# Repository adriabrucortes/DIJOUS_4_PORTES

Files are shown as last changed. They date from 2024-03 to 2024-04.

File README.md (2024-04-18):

View this project on [CADLAB.io](https://cadlab.io/project/27987). 

# Projecte Eines de Disseny - PORTES
#### Adrià Brú, Miquel Limón, Lluís Pujadas

## Especificacions/Components

| Type | Name | Datasheet | Link | Price |
| --- | --- | --- | --- | --- |
| uC | PIC32MK0256MCJ048 | [uC](https://ww1.microchip.com/downloads/aemDocuments/documents/MCU32/ProductDocuments/DataSheets/PIC32MK-General-Purpose-and-Motor-Control-With-CAN-FD-Family-DataSheet-D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) | [Mouser](https://www.mouser.es/ProductDetail/Microchip-Technology/PIC32MK0256MCJ048-E-Y8X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) | 7,37 € |
| LDO 3.3V (3A) | LT1528CT#PBF | [LDO](https://rocelec.widen.net/view/pdf/nbjrjihvdn/LITCS09222-1.pdf?t.download=true&u=5oefqw) | [Digikey](https://www.digikey.es/en/products/detail/rochester-electronics-llc/LT1528CT-PBF/13481919) | 5,75 € |
| Motor (588Nm, 280mA) | HG37-200-AA-00 | [motor](https://www.mouser.es/datasheet/2/972/hg37-2525173.pdf) | [Mouser](https://www.mouser.es/ProductDetail/Nidec-Components/HG37-200-AA-00?qs=Wj%2FVkw3K%252BMBRymxOaiVRvg%3D%3D) | 26,74 € |
| CAN Transciever | TCAN3413DR | [can](https://www.ti.com/lit/ds/symlink/tcan3414.pdf?ts=1711721678762&ref_url=https%253A%252F%252Fwww.mouser.it%252F) | [Mouser](https://www.mouser.es/ProductDetail/Texas-Instruments/TCAN3413DR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) | 2,41 € |
| Crystal Osc | ECS-3225SMV-080-GP-TR | [clk](https://www.mouser.es/datasheet/2/122/ECS_3225SMV-1623609.pdf) | [Mouser](https://www.mouser.es/ProductDetail/ECS/ECS-3225SMV-080-GP-TR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) | 1,92 € |
| Driver (3.5A, +csense) | MAX22201ATC+ | [driver](https://www.mouser.es/datasheet/2/609/MAX22201_MAX22207-3127854.pdf) | [Mouser](https://www.mouser.es/ProductDetail/Analog-Devices-Maxim-Integrated/MAX22201ATC%2b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) | 1,56 € |
| ~~Current sensor (75A)~~ | ~~TMCS1123B2AQDVGR~~  | ~~[csense](https://www.ti.com/lit/ds/symlink/tmcs1123.pdf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)~~ | ~~[Mouser](https://www.mouser.es/ProductDetail/Texas-Instruments/TMCS1123B2AQDVGR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)~~ | ~~5,63 €~~ |
| Zener 12V (150MW) | DDZ9699T-7 | [zener](https://eu.mouser.com/datasheet/2/115/DIOD_S_A0003550665_1-2542209.pdf) | [Mouser](https://eu.mouser.com/ProductDetail/Diodes-Incorporated/DDZ9699T-7?qs=mQbszxtPdlOBwg08InvD3Q%3D%3D) | 0,41 € |
| Díode | BYV10MX-600PQ | [diode](https://eu.mouser.com/datasheet/2/848/BYV10MX_600P-2401273.pdf) | [Mouser](https://eu.mouser.com/ProductDetail/WeEn-Semiconductors/BYV10MX-600PQ?qs=QNEnbhJQKvYwaGjd%2F4%252BPWg%3D%3D) | 0,54 € |
| RFID | DLP-RFID2 | [rfid](https://mm.digikey.com/Volume0/opasdata/d220001/medias/docus/5656/DLP-RFID2%28D%29-V2.pdf) | [Digikey](https://www.digikey.es/en/products/detail/dlp-design-inc/DLP-RFID2/3770244) | 35,04 € |
| Motor lineal (150N, 2A) (opc) | DLA-12-5-A-50-IP65 | [motor-lineal](https://www.transmotec.com/Download/Catalog/Transmotec-EN-DLA-2022.pdf) | [Transmotec](https://www.transmotec.com/product/dla-12-5-a-50-pot-ip65/) | 303,5 € |
| Final de Carrera  (5V) | ESE-22MV21T | [Final-Carrera](https://industrial.panasonic.com/cdbs/www-data/pdf/ATB0000/ATB0000C12.pdf) | [Digikey](https://www.digikey.es/en/products/detail/panasonic-electronic-components/ESE-22MV21T/1245478) | 0,42 € |
| DC/DC 5V (2A, +/-49.5mV) | P7805-2000R-S | [dcdc2A](https://eu.mouser.com/datasheet/2/670/p78_2000r_s-3070500.pdf) | [Mouser](https://eu.mouser.com/ProductDetail/CUI-Inc/P7803-2000R-S?qs=vvQtp7zwQdObalelOc2Obw%3D%3D) | 5,53 € |
| DC/DC 3.3V (3A, +/-33.3mV) | P783-Q24-S3-S | [dcdc3A](https://eu.mouser.com/datasheet/2/670/p783_s-1889817.pdf) | [Mouser](https://eu.mouser.com/ProductDetail/CUI-Inc/P783-Q24-S3-S?qs=sPbYRqrBIVl7G8uy4wpmww%3D%3D) | 15,07 € |
| C Tan 1u 20V 3216-18 | T491A105K020AT4360 | [ctant1u](https://eu.mouser.com/datasheet/2/447/KEM_T2005_T491-3316937.pdf) | [Mouser](https://eu.mouser.com/ProductDetail/KEMET/T491A105K020AT4360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) | 0,07 € |
| C Cer 22u 10V 1206 | CL31B226KPHNNWE | [cer22u](https://eu.mouser.com/datasheet/2/585/MLCC-1837944.pdf) | [Mouser](https://eu.mouser.com/ProductDetail/Samsung-Electro-Mechanics/CL31B226KPHNNWE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) | 0,086 € |
| C Cer 22u 50V | KTS500B226M76N0T00 | [ccer22u50v](https://eu.mouser.com/datasheet/2/420/nipc_s_a0010886389_1-2285932.pdf) | [Mouser](https://eu.mouser.com/ProductDetail/Chemi-Con/KTS500B226M76N0T00?qs=yFwz03cOJpkGGSneI4ka0Q%3D%3D) | 3,58 € |
| C Cer 10n 25V 1206 | KAM31BR81H103KT | [ccer10n50v](https://eu.mouser.com/datasheet/2/40/AutoMLCCKAM-3216307.pdf) | [Mouser](https://eu.mouser.com/ProductDetail/KYOCERA-AVX/KAM31BR81H103KT?qs=Jm2GQyTW%2FbjzijSUJGW%2FJA%3D%3D) | 0,28 € |
| C Ele 4.7u 35V | 865080540002 | [cele4.7u](https://www.we-online.com/components/products/datasheet/865080540002.pdf) | [Mouser](https://eu.mouser.com/ProductDetail/Wurth-Elektronik/865080540002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) | 0,17 € |
| C Ele 47u 16V | 860010372004 | [cele74u](https://www.we-online.com/components/products/datasheet/860010372004.pdf) | [Mouser](https://www.mouser.es/ProductDetail/Wurth-Elektronik/860010372004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) | 0,09 € |
| C Cer 1u 25V 0805 | C0805C105K3RAC | [cer1u25v](https://www.mouser.es/datasheet/2/447/KEM_C1002_X7R_SMD-3316098.pdf) | [Mouser](https://www.mouser.es/ProductDetail/KEMET/C0805C105K3RAC?qs=ycRbFa0SLRQpHhAu2LUs4g%3D%3D) | 0,021 € |
| C Cer 0.1u 50V 0805 | C0805C104M5RAC | [cer100n0805](https://eu.mouser.com/datasheet/2/447/KEM_C1002_X7R_SMD-3316098.pdf) | [Mouser](https://eu.mouser.com/ProductDetail/KEMET/C0805C104M5RAC?qs=VOOUd%252Bza08rWzt4y8eXMuQ%3D%3D) | 0,008 € |
| C Cer 21p 50V 01005 | GRM0225C1H210GA02L | [cer21p01005](https://eu.mouser.com/datasheet/2/281/murata_03052018_GRM_Series_1-1310166.pdf) | [Mouser](https://eu.mouser.com/ProductDetail/Murata-Electronics/GRM0225C1H210GA02L?qs=qkDYIeTQ%252BEl6hnZ3ixEkiA%3D%3D) | 0,09 € |
| R 120 125mW 0805 | CQ05WAF1200T5E | [r120](https://www.mouser.es/datasheet/2/1365/10-3358738.pdf) | [Mouser](https://www.mouser.es/ProductDetail/Royalohm/CQ05WAF1200T5E?qs=sGAEpiMZZMtlubZbdhIBINZaoL9yqB51WBf9LviuJYE%3D) | 0,002 € |
| R 1k 125mW 0805 | TC05W8F1001T5G | [r1k](https://eu.mouser.com/datasheet/2/1365/21-3077223.pdf) | [Mouser](https://eu.mouser.com/ProductDetail/Royalohm/TC05W8F1001T5G?qs=ST9lo4GX8V0X3zBMraFh1A%3D%3D) | 0,007 € |
| R 330 125mW 0805 | TC0550F3300T5F | [r330](https://eu.mouser.com/datasheet/2/1365/21-3077223.pdf) | [Mouser](https://eu.mouser.com/ProductDetail/Royalohm/TC0550F3300T5F?qs=T%252BzbugeAwjgeSBQZlDaTmA%3D%3D) | 0,007 € |
| R 10k 0.25W 0805 | RNCP0805JTD10K0 | [r10k](https://eu.mouser.com/datasheet/2/385/SEI_rncp-3077653.pdf) | [Mouser](https://eu.mouser.com/ProductDetail/SEI-Stackpole/RNCP0805JTD10K0?qs=IPgv5n7u5QaJFxYpOecM6A%3D%3D) | 0,007 € |
| R 100k 125mW 0805 | TC0550F1003T5G | [r100k](https://eu.mouser.com/datasheet/2/1365/Royalohm_09132021_9__Thin_Film_20200106-2580434.pdf) | [Mouser](https://eu.mouser.com/ProductDetail/Royalohm/TC0550F1003T5G?qs=Wj%2FVkw3K%252BMBYxpaKle1zIA%3D%3D) | 0,007 € |
| R 33k 125mW 0805 | TC0550D3302T5G | [r33k](https://eu.mouser.com/datasheet/2/1365/Royalohm_09132021_9__Thin_Film_20200106-2580434.pdf) | [Mouser](https://eu.mouser.com/ProductDetail/Royalohm/TC0550D3302T5G?qs=Wj%2FVkw3K%252BMB5M6MpcX7%252Byw%3D%3D) | 0,008 € |

## Diagrama de blocs
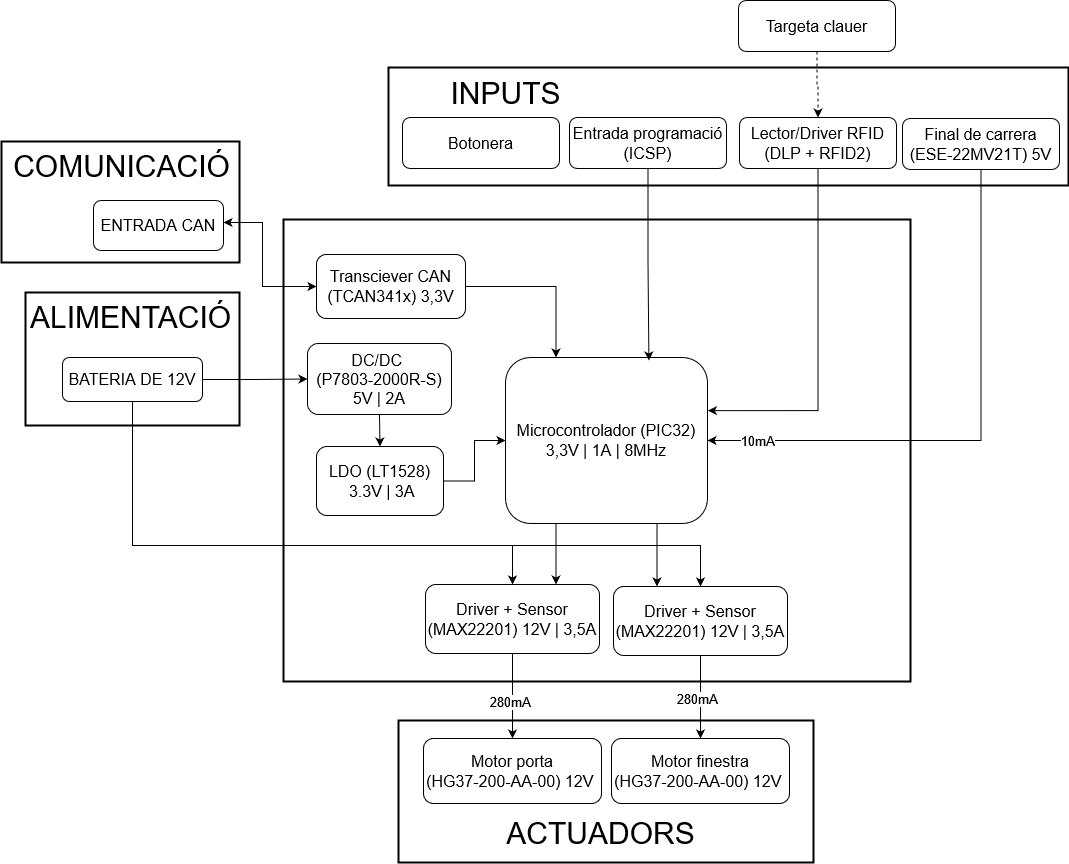
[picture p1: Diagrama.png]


## To Do
- [x] Add buttons
- [x] Add power input protection
- [x] Add controls
- [x] Resize boxes to same size (diagram)
- [x] Change "targeta" to "targeta clauer"
- [x] Restructure schematic for simplicity
- [x] Add buttons to schematic
- [x] Add expression for R (ISENSE)
- [x] Change regulator to DC/DC (maybe + regulator)
- [x] PCB v1
- [x] Change 2nd crystal to 32kHz (instead of 8MHz)
- [x] Correct via errors (DRC)
- [x] Solve pcb model compatibility issues
- [x] Rearrange power components
- [x] Remove SPI
- [ ] Make budget for different production quantities
- [ ] Correct silkscreen

## Changelogs
### 03/04
- Schematic done
- Corrected block diagram
	- Added additional data
	- Deleted 12V LDO
	- Changed current sensor for integrated Driver+Sensor
 
### 04/04
- Swapped regulator for DC/DC
- Add expression for R (ISENSE)
- Change regulator to DC/DC (maybe + regulator)
- Restructure schematic for simplicity
- Added 1 extra bit for window control

### 05/04 
- Added all components
- PWR plane done (v1)

### 06/04
- Corrected PWR
- Started digital

### 08/04
- Corrected diagram
- Changed from DC/DC to DC/DC (5V) + LDO (3,3V)
- Change second Clk to 32kHz
- Delete JTAG
- Correct oscillator connections

### 09/04
- Preliminar PCB done
- Added name to file
  
### 10/04
- Solved DRC
- Added names to board

### 11/04
- Changed SMD capacitors to ceramic

### 13/04
- Rearranged microcontroller pins

### 14/04
- Rearranged PCB to reduce through-holes

### 16/04
- Rearranged power stage

### 17/04
- Switched decoupling capacitors to back layer

### 18/04
- Solve DRC errors,
- Restructure 
- Change decoupling capacitors to bottom layer
- Corrections suggested by Joan

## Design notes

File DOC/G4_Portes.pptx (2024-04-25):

## Eines de Disseny Grup 4 - Portes

Adrià Brú Cortés
Miquel Limón Vallés
Lluís Pujadas Prat

## Objectius

- Controlar la pujada i baixada de les finestres d’un cotxe, així com l’obertura i tancament de les portes.
- Comunicar-se amb un agent extern (clau de cotxe) de forma inalàmbrica mitjançant RFID.
- Aturar la pujada de les finestres en detectar un pic de corrent.

## Diagrama de Blocs

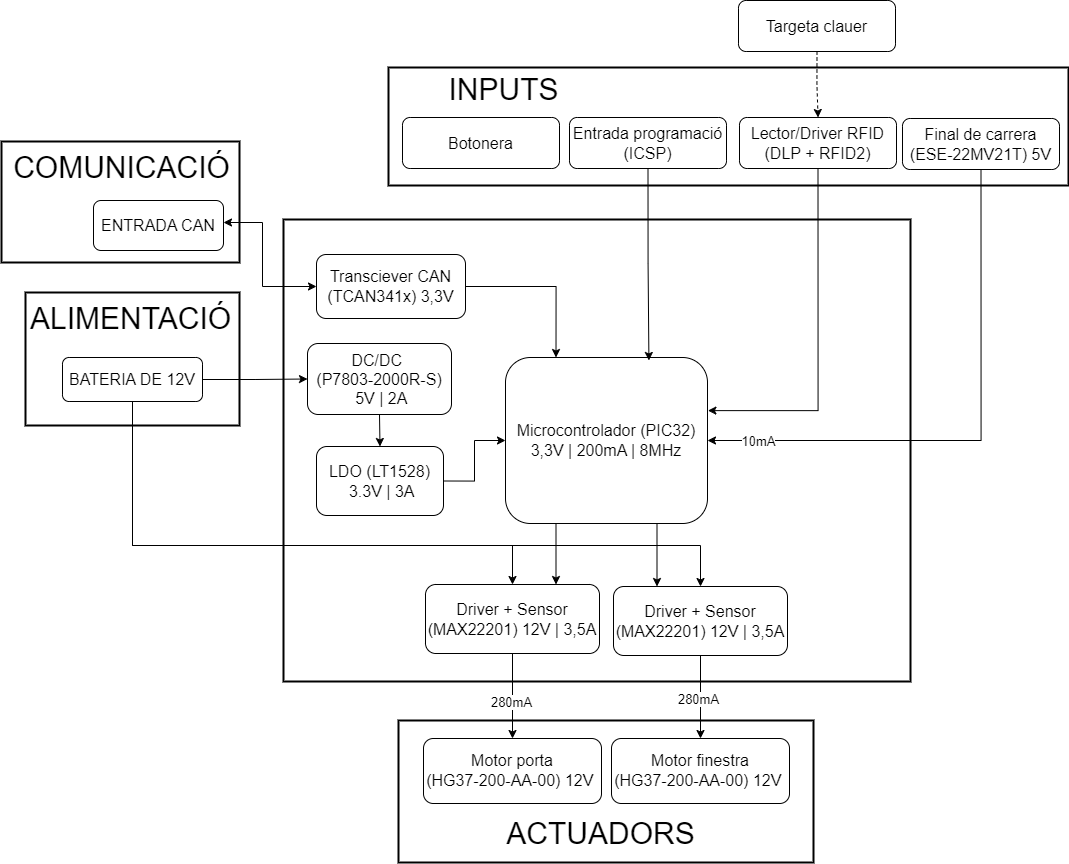
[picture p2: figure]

## Esquemàtic - Alimentació

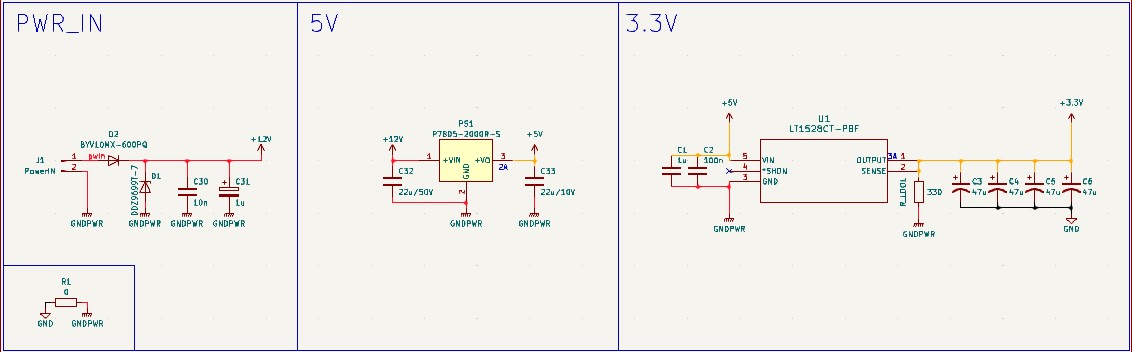
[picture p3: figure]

## Esquemàtic - Digital

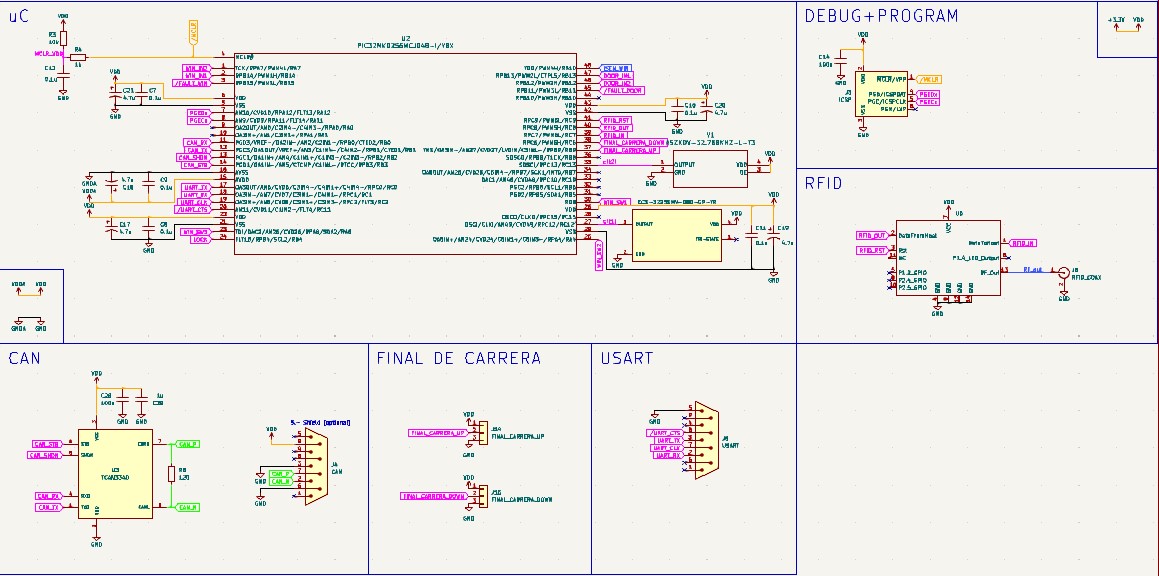
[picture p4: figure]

## Esquemàtic - Actuadors

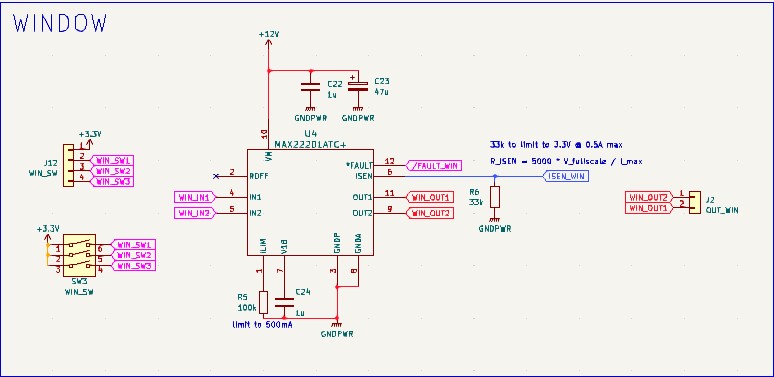
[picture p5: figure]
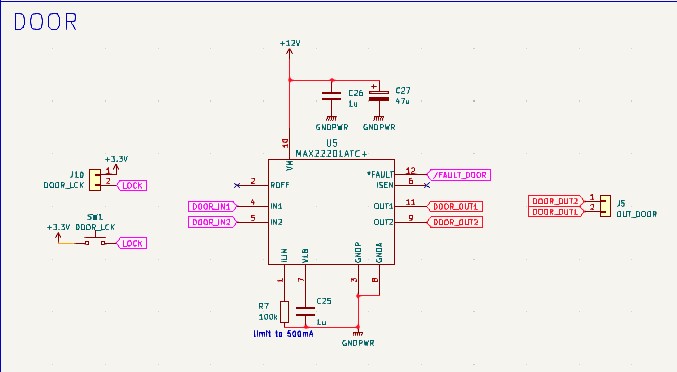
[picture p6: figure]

## Layout

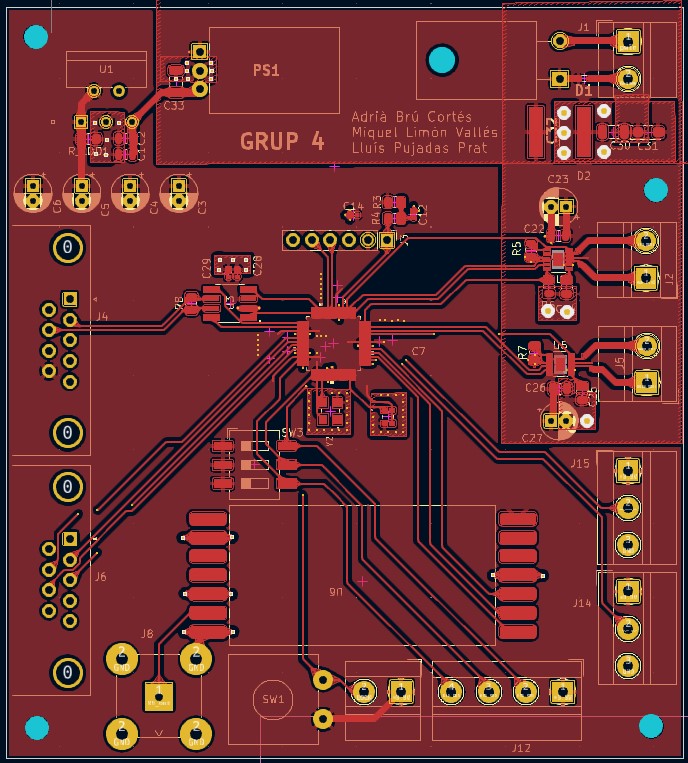
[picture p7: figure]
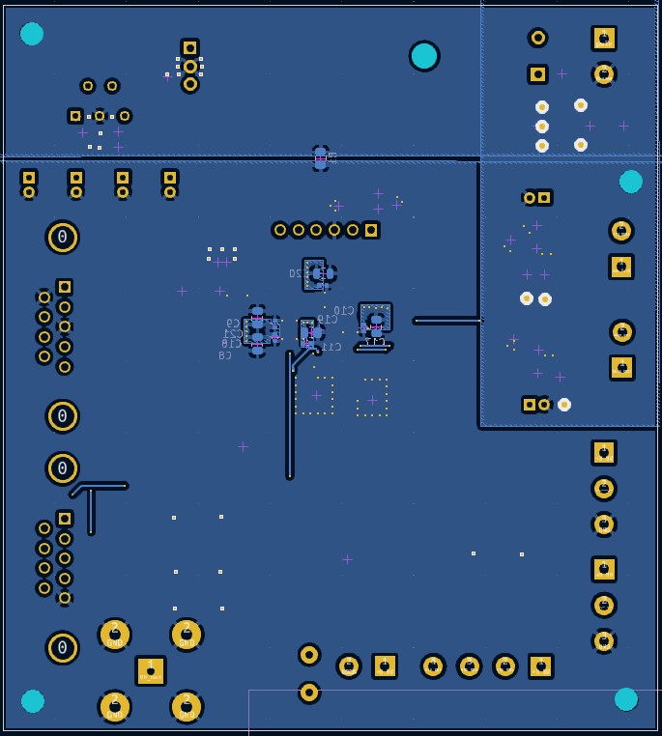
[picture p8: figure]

## Model 3D

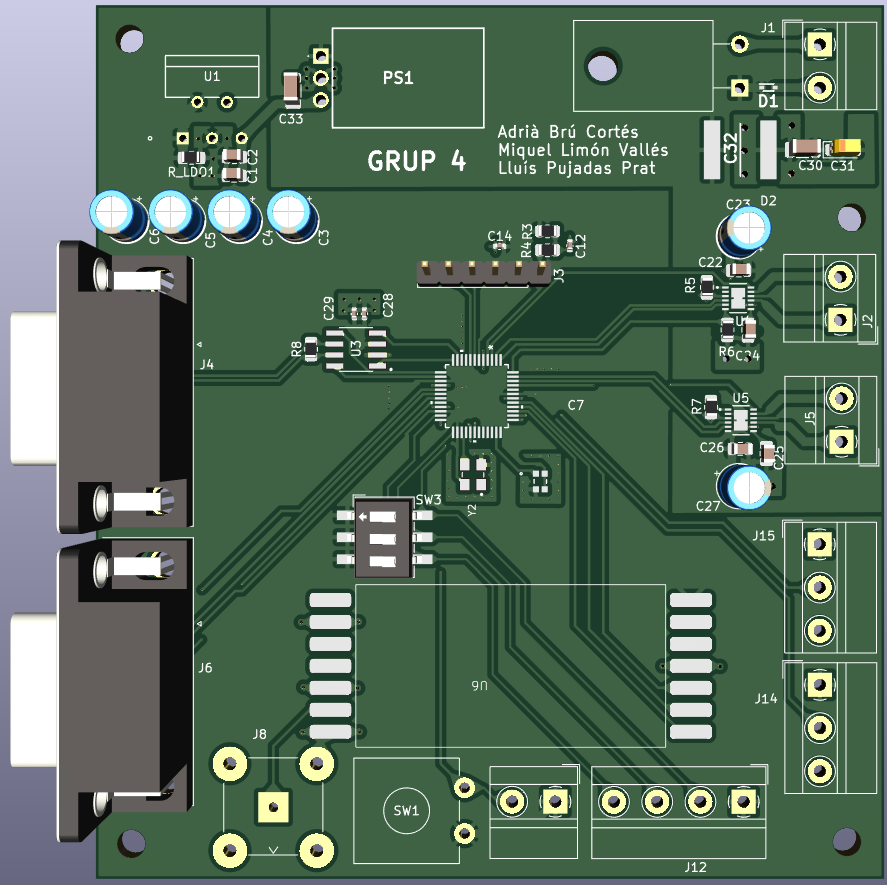
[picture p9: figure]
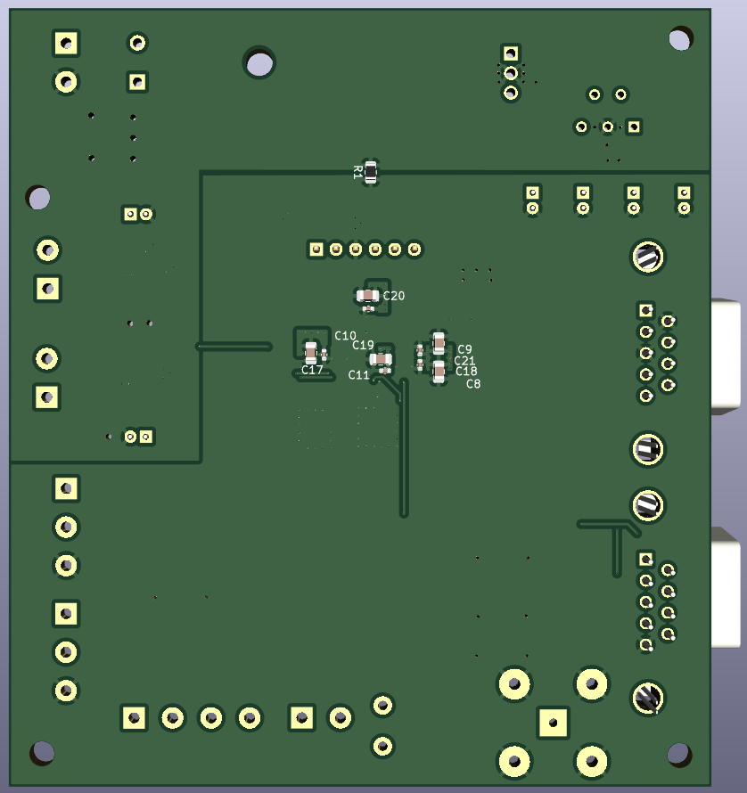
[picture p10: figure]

## Pressupost

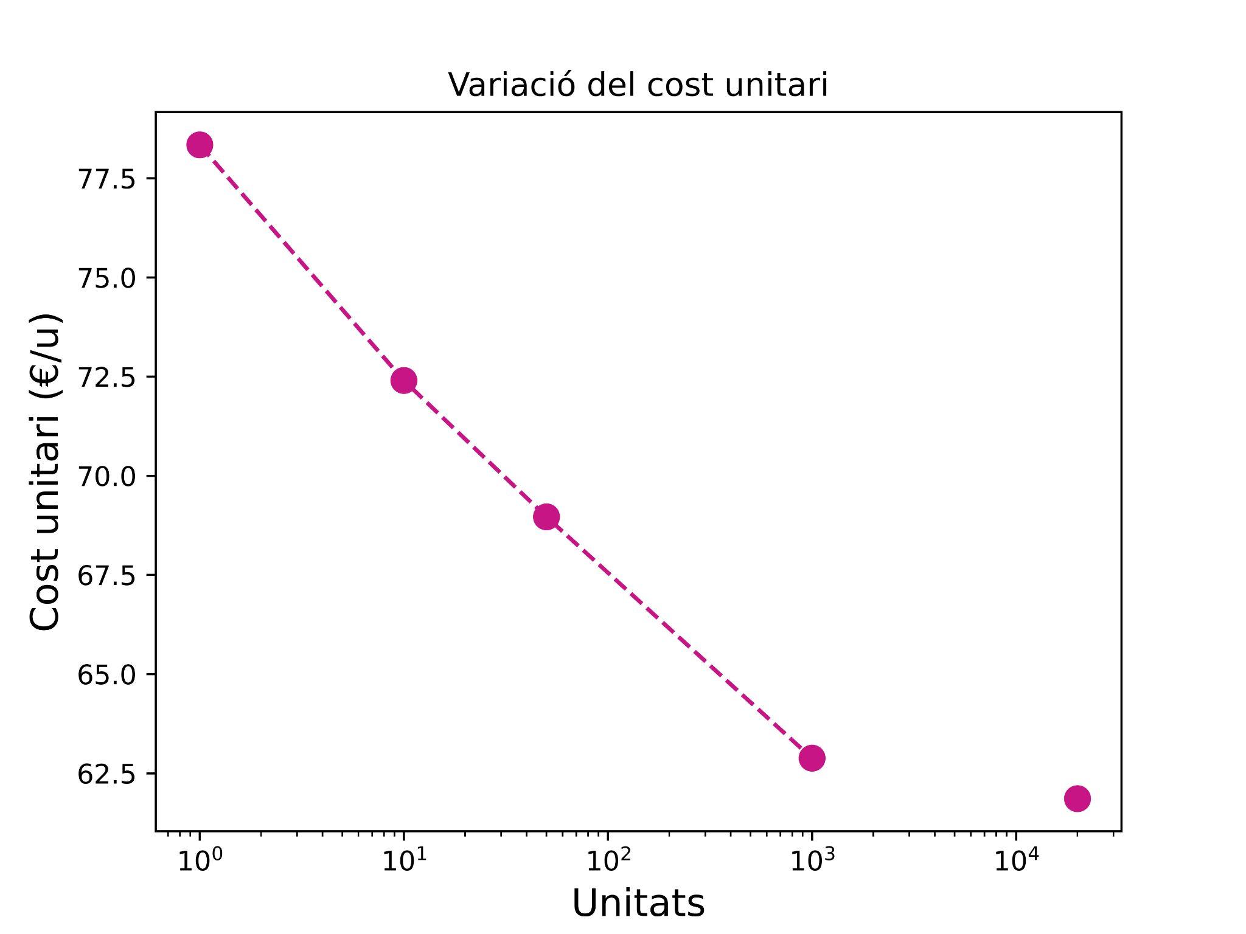
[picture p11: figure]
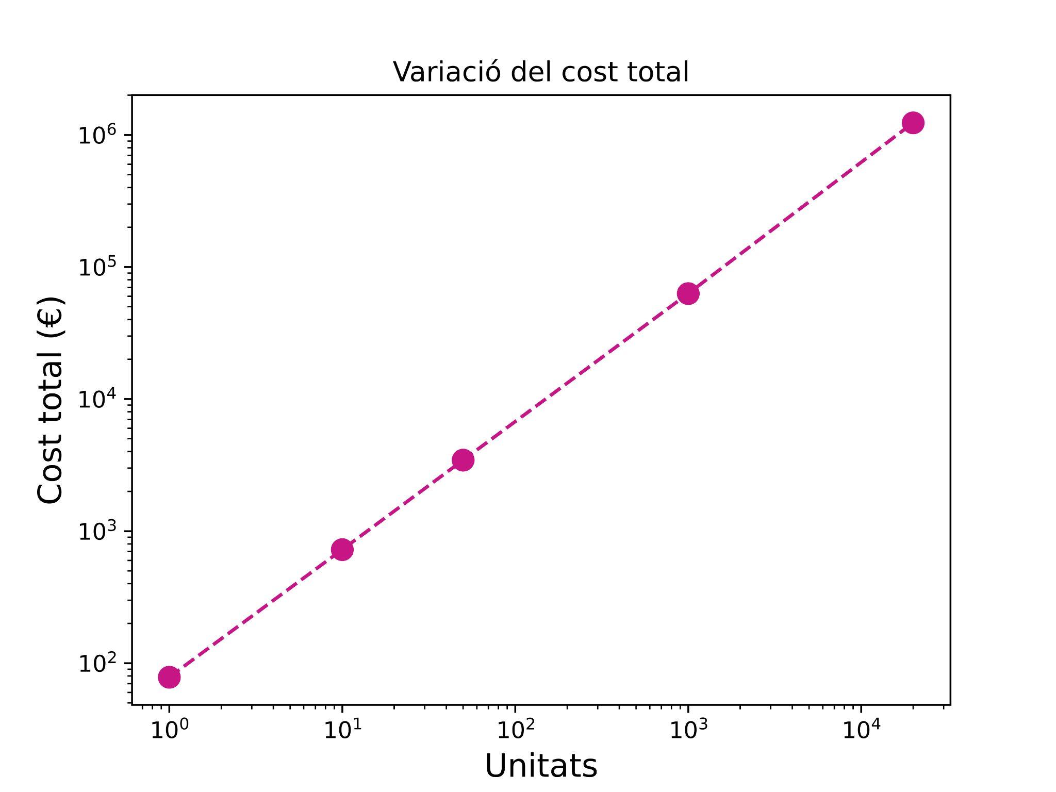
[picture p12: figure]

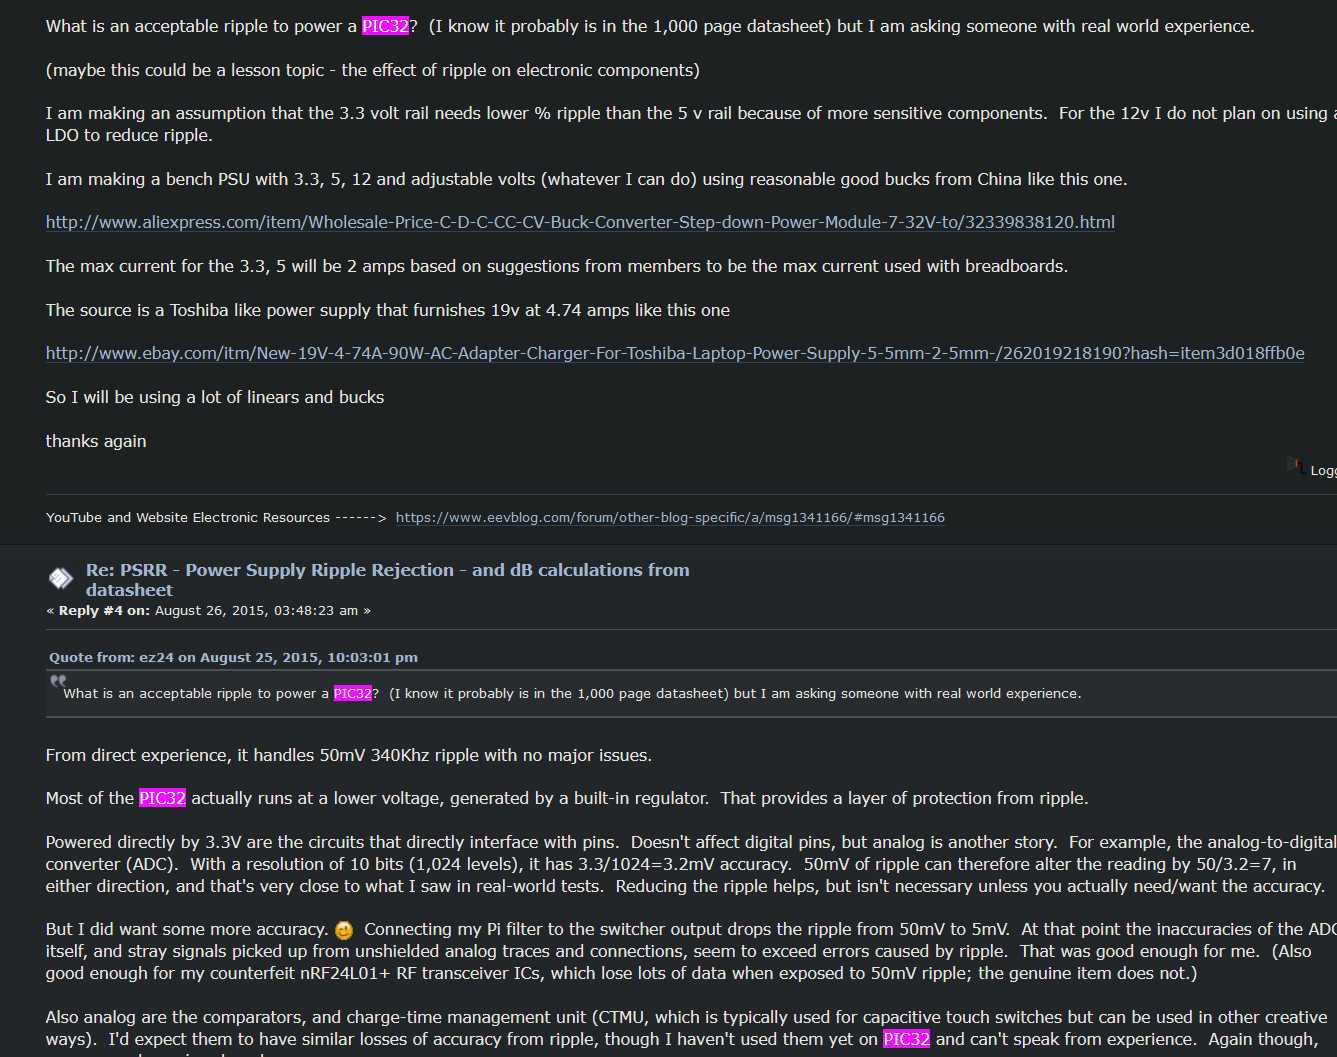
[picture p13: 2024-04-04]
DIJOUS_4_PORTES-master/DOC/ripple_pic32.png

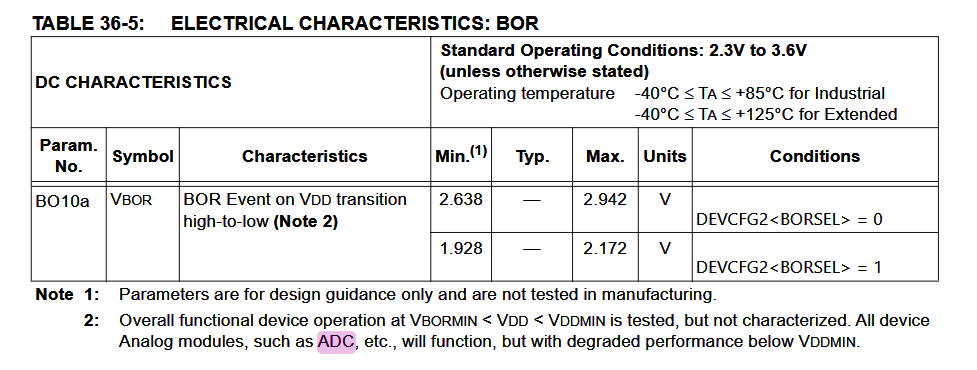
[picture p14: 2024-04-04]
DOC/vbor.png

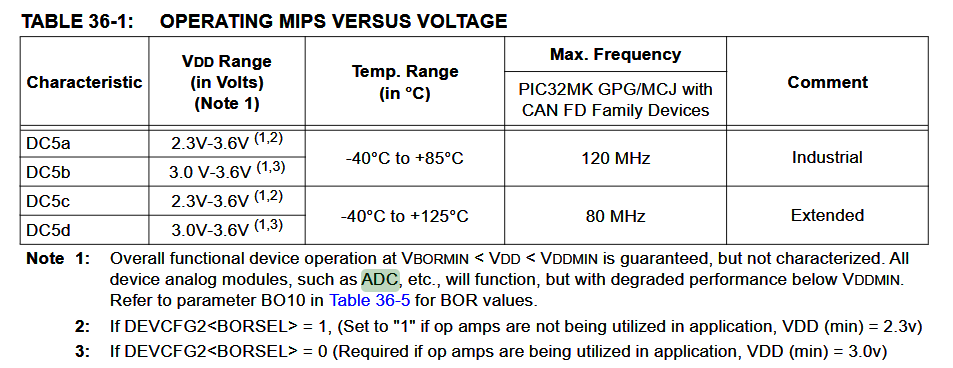
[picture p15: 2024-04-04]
DOC/dc_char.png

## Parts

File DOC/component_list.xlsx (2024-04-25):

 |  |  |  |  | 1xPCB |  | 10xPCB |  | 50xPCB |  | 1000xPCB |  | 20000xPCB
Components | Name | Datasheet | Link | Units/PCB | Cost per unit (€) | Order cost (€) | Cost per unit (€) | Order cost (€) | Cost per unit (€) | Order cost (€) | Cost per unit (€) | Order cost (€) | Cost per unit (€) | Order cost (€)
uC | PIC32MK0256MCJ048 | uC (https://ww1.microchip.com/downloads/aemDocuments/documents/MCU32/ProductDocuments/DataSheets/PIC32MK-General-Purpose-and-Motor-Control-With-CAN-FD-Family-Data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) | Mouser (https://www.mouser.es/ProductDetail/Microchip-Technology/PIC32MK0256MCJ048-E-Y8X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) | 1 | 7.37 | 7.37 | 7.37 | 73.7 | 6.76 | 338 | 6.12 | 6120 | 6.12 | 122400
LDO 3.3V (3A) | LT1528CT#PBF | LDO (https://rocelec.widen.net/view/pdf/nbjrjihvdn/LITCS09222-1.pdf?t.download=true&u=5oefqw) | Digikey (https://www.digikey.es/en/products/detail/rochester-electronics-llc/LT1528CT-PBF/13481919) | 1 | 5.7528 | 5.7528 | 5.7528 | 57.528 | 5.7528 | 287.64 | 5.7528 | 5752.8 | 5.7528 | 115056
CAN Transciever | TCAN3413DR | can (https://www.ti.com/lit/ds/symlink/tcan3414.pdf?ts=1711721678762) | Mouser (https://www.mouser.es/ProductDetail/Texas-Instruments/TCAN3413DR) | 1 | 2.41 | 2.41 | 2.17 | 21.7 | 2.17 | 108.5 | 1.18 | 1180 | 1.01 | 20200
Crystal Osc | ECS-3225SMV-080-GP-TR | clk (https://www.mouser.es/datasheet/2/122/ECS_3225SMV-1623609.pdf) | Digikey (https://www.digikey.es/es/products/detail/ecs-inc/ECS-3225SMV-080-GP-TR/10325283) | 1 | 1.92029 | 1.92029 | 1.92029 | 19.2029 | 1.92029 | 96.0145 | 1.92029 | 1920.29 | 1.92029 | 38405.8
Crystal Osc | ASZKDV_ABR | clk (https://www.mouser.es/datasheet/2/3/ASZKDV-3240426.pdf) | Mouser (https://www.mouser.es/ProductDetail/ABRACON/ASZKDV-32.768kHz-L-T3?qs=1Kr7Jg1SGW8063pU72DBew%3D%3D) | 1 | 2.24 | 2.24 | 2.19 | 21.9 | 2.08 | 104 | 1.53 | 1530 | 1.34 | 26800
Driver (3.5A, +csense) | MAX22201ATC+ | driver (https://www.mouser.es/datasheet/2/609/MAX22201_MAX22207-3127854.pdf) | Mouser (https://www.mouser.es/ProductDetail/Analog-Devices-Maxim-Integrated/MAX22201ATC%2B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) | 2 | 1.8 | 3.6 | 1.61 | 32.2 | 1.35 | 135 | 1.04 | 2080 | 1.04 | 41600
Zener 12V (150MW) | DDZ9699T-7 | zener (https://eu.mouser.com/datasheet/2/115/DIOD_S_A0003550665_1-2542209.pdf) | Mouser (https://eu.mouser.com/ProductDetail/Diodes-Incorporated/DDZ9699T-7?qs=mQbszxtPdlOBwg08InvD3Q%3D%3D) | 1 | 0.41 | 0.41 | 0.278 | 2.78 | 0.278 | 13.9 | 0.09 | 90 | 0.057 | 1140
Díode | BYV10MX-600PQ | diode (https://eu.mouser.com/datasheet/2/848/BYV10MX_600P-2401273.pdf) | Mouser (https://eu.mouser.com/ProductDetail/WeEn-Semiconductors/BYV10MX-600PQ?qs=QNEnbhJQKvYwaGjd%2F4%252BPWg%3D%3D) | 1 | 0.54 | 0.54 | 0.457 | 4.57 | 0.457 | 22.85 | 0.201 | 201 | 0.158 | 3160
RFID | DLP-RFID2 | rfid (https://mm.digikey.com/Volume0/opasdata/d220001/medias/docus/5656/DLP-RFID2%28D%29-V2.pdf) | Digikey (https://www.digikey.es/en/products/detail/dlp-design-inc/DLP-RFID2/3770244) | 1 | 35.04 | 35.04 | 35.04 | 350.4 | 35.04 | 1752 | 35.04 | 35040 | 35.04 | 700800
Final de Carrera (5V) | ESE-22MV21T | Final-Carrera (https://industrial.panasonic.com/cdbs/www-data/pdf/ATB0000/ATB0000C12.pdf) | Digikey (https://www.digikey.es/en/products/detail/panasonic-electronic-components/ESE-22MV21T/1245478) | 2 | 0.42 | 0.84 | 0.404 | 8.08 | 0.3304 | 33.04 | 0.25096 | 501.92 | 0.20356 | 8142.4
DC/DC 5V (2A, +/-49.5mV) | P7805-2000R-S | dcdc2A (https://eu.mouser.com/datasheet/2/670/p78_2000r_s-3070500.pdf) | Mouser (https://eu.mouser.com/ProductDetail/CUI-Inc/P7803-2000R-S?qs=vvQtp7zwQdObalelOc2Obw%3D%3D) | 1 | 5.53 | 5.53 | 5.38 | 53.8 | 5.06 | 253 | 4.43 | 4430 | 4.27 | 85400
C Tan 1u 20V 3216-18 | T491A105K020AT4360 | ctant1u (https://www.vishay.com/docs/40002/293d.pdf) | Mouser (https://www.mouser.es/ProductDetail/Vishay-Sprague/293D105X9020A2TE3?qs=wgO0AD0o1vvGvFnvINoEoQ%3D%3D) | 1 | 0.38 | 0.38 | 0.214 | 2.14 | 0.214 | 10.7 |  | 0 | 0.0068 | 136
C Cer 22u 10V 1206 | C1206C226M8PAC | cer22u (https://www.mouser.es/datasheet/2/447/KEM_C1006_X5R_SMD-3316465.pdf) | Mouser (https://www.mouser.es/ProductDetail/KEMET/C1206C226M8PAC) | 1 | 0.42 | 0.42 | 0.276 | 2.76 | 0.276 | 13.8 | 0.113 | 113 | 0.089 | 1780
C Cer 22u 50V | KTS500B226M76N0T00 | ccer22u50v (https://www.mouser.es/datasheet/2/420/nipc_s_a0010886389_1-2285932.pdf) | Mouser (https://eu.mouser.com/ProductDetail/Chemi-Con/KTS500B226M76N0T00?qs=yFwz03cOJpkGGSneI4ka0Q%3D%3D) | 1 | 3.59 | 3.59 | 3.05 | 30.5 | 2.76 | 138 | 1.87 | 1870 | 1.83 | 36600
C Cer 10n 25V 1206 | KAM31BR81H103KT | ccer10n50v (https://www.mouser.es/datasheet/2/40/AutoMLCCKAM-3216307.pdf) | Mouser (https://eu.mouser.com/ProductDetail/KYOCERA-AVX/KAM31BR81H103KT?qs=Jm2GQyTW%2FbjzijSUJGW%2FJA%3D%3D) | 1 | 0.28 | 0.28 | 0.187 | 1.87 | 0.187 | 9.35 | 0.069 | 69 | 0.054 | 1080
C Ele 4.7u 35V | GRM219R6YA475MA73D | cele4.7u (https://www.mouser.es/datasheet/2/281/1/GRM219R6YA475MA73_01A-1986343.pdf) | Mouser (https://www.mouser.es/ProductDetail/Murata-Electronics/GRM219R6YA475MA73D) | 5 | 0.19 | 0.95 | 0.091 | 4.55 | 0.053 | 13.25 | 0.043 | 215 | 0.028 | 2800
C Ele 47u 16V | 860010372004 | cele47u (https://www.we-online.com/components/products/datasheet/860010372004.pdf) | Mouser (https://www.mouser.es/ProductDetail/Wurth-Elektronik/860010372004) | 6 | 0.09 | 0.54 | 0.083 | 4.98 | 0.064 | 19.2 | 0.054 | 324 | 0.054 | 6480
C Cer 1u 25V 0805 | VJ0805Y104JXXAT | cer1u25v (https://www.mouser.es/datasheet/2/40/KGM_X7R-3223212.pdf) | Mouser (https://www.mouser.es/ProductDetail/KYOCERA-AVX/08053C105KAT2A) | 5 | 0.42 | 2.1 | 0.222 | 11.1 | 0.063 | 15.75 | 0.085 | 425 | 0.081 | 8100
C Cer 0.1u 50V 0402 | 0402X7R104KT2AT | cer100n0402 (https://www.mouser.es/datasheet/2/40/General_Purpose_Capacitors-3314795.pdf) | Mouser (https://www.mouser.es/ProductDetail/KYOCERA-AVX/0402X7R104KT2AT) | 6 | 0.29 | 1.74 | 0.195 | 11.7 | 0.117 | 35.1 | 0.078 | 468 | 0.061 | 7320
R 120 125mW 0805 | CQ05WAF1200T5E | r120 (https://eu.mouser.com/datasheet/2/447/PYu_RT_1_to_0_01_RoHS_L_12-3003070.pdf) | Digikey (https://www.digikey.es/es/products/detail/panasonic-electronic-components/ERA-3AEB121V/1465832) | 1 | 0.12 | 0.12 | 0.09 | 0.9 | 0.0718 | 3.59 | 0.04332 | 43.32 | 0.02824 | 564.8
R 1k 125mW 0805 | TC05W8F1001T5G | r1k (https://eu.mouser.com/datasheet/2/447/PYu_RT_1_to_0_01_RoHS_L_12-3003070.pdf) | Digikey (https://www.digikey.es/es/products/detail/stackpole-electronics-inc/RNCP1206FTD1K00/2240337) | 1 | 0.09 | 0.09 | 0.032 | 0.32 | 0.0266 | 1.33 | 0.01721 | 17.21 | 0.01161 | 232.2
R 330 125mW 0805 | TC0550F3300T5F | r330 (https://eu.mouser.com/datasheet/2/447/PYu_RT_1_to_0_01_RoHS_L_12-3003070.pdf) | Digikey (https://www.digikey.es/es/products/detail/yageo/RC1206JR-07330RL/729279) | 1 | 0.09 | 0.09 | 0.032 | 0.32 | 0.0208 | 1.04 | 0.01046 | 10.46 | 0.00686 | 137.2
R 10k 0.25W 0805 | RC1206FR-0710KL | r10k (https://eu.mouser.com/datasheet/2/54/CRM0805_1206_2010-3007277.pdf) | Digikey (https://www.digikey.es/es/products/detail/yageo/RC1206FR-0710KL/728483) | 1 | 0.09 | 0.09 | 0.035 | 0.35 | 0.0226 | 1.13 | 0.01152 | 11.52 | 0.00765 | 153
R 100k 125mW 0805 | ERJ-8ENF1003V | r100k (https://eu.mouser.com/datasheet/2/447/PYu_RT_1_to_0_01_RoHS_L_12-3003070.pdf) | Digikey (https://www.digikey.es/es/products/detail/panasonic-electronic-components/ERJ-8ENF1003V/89306) | 2 | 0.17 | 0.34 | 0.084 | 1.68 | 0.0564 | 5.64 | 0.03031 | 60.62 | 0.02099 | 839.6
R 33k 125mW 0805 | RC1206JR-0733KL | r33k (https://eu.mouser.com/datasheet/2/447/PYu_RT_1_to_0_01_RoHS_L_12-3003070.pdf) | Digikey (https://www.digikey.es/es/products/detail/yageo/RC1206JR-0733KL/729282) | 1 | 0.09 | 0.09 | 0.032 | 0.32 | 0.0208 | 1.04 | 0.01046 | 10.46 | 0.00686 | 137.2
Current sensor (75A) | TMCS1123B2AQDVGR | csense (https://www.ti.com/lit/ds/symlink/tmcs1123.pdf?ts=1711707167099) | Mouser (https://www.mouser.es/ProductDetail/Texas-Instruments/TMCS1123B2AQDVGR) | NOT USED | - | - | - | - | - | - | - | - | - | -
DC/DC 3.3V (3A, +/-33.3mV) | P783-Q24-S3-S | dcdc3A (https://eu.mouser.com/datasheet/2/670/p783_s-1889817.pdf) | Mouser (https://eu.mouser.com/ProductDetail/CUI-Inc/P783-Q24-S3-S?qs=sPbYRqrBIVl7G8uy4wpmww%3D%3D) | NOT USED | - | - | - | - | - | - | - | - | - | -
Motor (588Nm, 280mA) | HG37-200-AA-00 | motor (https://www.mouser.es/datasheet/2/972/hg37-2525173.pdf) | Mouser (https://www.mouser.es/ProductDetail/Nidec-Components/HG37-200-AA-00?qs=Wj%2FVkw3K%252BMBRymxOaiVRvg%3D%3D) | 2 | 26.74 | 53.48 | 24.31 | 486.2 | 23.8 | 2380 | 23.3 | 46600 | 23.05 | 922000
Motor lineal (150N, 2A) (opc) | DLA-12-5-A-50-IP65 | motor-lineal (https://www.transmotec.com/Download/Catalog/Transmotec-EN-DLA-2022.pdf) | Transmotec (https://www.transmotec.com/product/dla-12-5-a-50-pot-ip65/) | NOT USED | - | - | - | - | - | - | - | - | - | -
 | PCBs | 1 | 10 | 50 | 1000 | 20000
 | Preu Stencils (€) | NOT USED | NOT USED | 6.55 | 6.55 | 131 | Assumim 1000 usos/stencil
 | Preu fabricació PCBs (€) | 1.87 | 4.68 | 28.81 | 391.37 | 7640
 | Preu Total PCB (€) | 78.34309 | 724.0309 | 3448.2245 | 62881.52 | 1237235.2
 | Preu unitari PCB (€) | 78.34309 | 72.40309 | 68.96449 | 62.88152 | 61.86176
 |  | JLCPCB fabrica com a mínim 5 pcbs, per aquest preu se’n tenen 5

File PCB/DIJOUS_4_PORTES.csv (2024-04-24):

Id | Identificador | Huella | Cantidad | Identificación | Suministrador y ref
1 | R5,R7 | R_0805_2012Metric | 2 | 100k
2 | C22,C26,C24,C25,C1 | C_0805_2012Metric | 5 | 1u
3 | J8 | BNC_TEConnectivity_1478035_Horizontal | 1 | RFID_COAX
4 | Y2 | OSC_ECS-3225SMV-080-GP-TR | 1 | ECS-3225SMV-080-GP-TR
5 | PS1 | P78032000RS | 1 | P7805-2000R-S
6 | C32 | CAPC7563X400N | 1 | 22u/50V
7 | J15 | TerminalBlock_MetzConnect_Type011_RT05503HBWC_1x03_P5.00mm_Horizontal | 1 | FINAL_CARRERA_DOWN
8 | C29 | C_0402_1005Metric | 1 | 1u
9 | U5,U4 | MAX22201ATC_ | 2 | MAX22201ATC+
10 | D2 | TO-220F-2_Horizontal_TabDown | 1 | BYV10MX-600PQ
11 | J5 | TerminalBlock_MetzConnect_Type011_RT05502HBWC_1x02_P5.00mm_Horizontal | 1 | OUT_DOOR
12 | J14 | TerminalBlock_MetzConnect_Type011_RT05503HBWC_1x03_P5.00mm_Horizontal | 1 | FINAL_CARRERA_UP
13 | J4 | DSUB-9_Male_Horizontal_P2.77x2.84mm_EdgePinOffset4.94mm_Housed_MountingHolesOffset7.48mm | 1 | CAN
14 | D1 | SODFL1608X65N | 1 | DDZ9699T-7
15 | Y1 | ASZKDV_ABR | 1 | ASZKDV-32.768KHZ-L-T3
16 | C31 | CP_EIA-3216-18_Kemet-A | 1 | 1u
17 | J10 | TerminalBlock_MetzConnect_Type011_RT05502HBWC_1x02_P5.00mm_Horizontal | 1 | DOOR_LCK
18 | C6,C4,C23,C5,C3,C27 | CP_Radial_D5.0mm_P2.00mm | 6 | 47u
19 | R6 | R_0805_2012Metric | 1 | 33k
20 | J3 | PinHeader_1x06_P2.54mm_Vertical | 1 | ICSP
21 | J2 | TerminalBlock_MetzConnect_Type011_RT05502HBWC_1x02_P5.00mm_Horizontal | 1 | OUT_WIN
22 | C33 | C_1206_3216Metric | 1 | 22u/10V
23 | R4 | R_0805_2012Metric | 1 | 1k
24 | U2 | PIC32MK0256MCJ048-I-Y8X_MCH | 1 | PIC32MK0256MCJ048-I/Y8X
25 | C12,C10,C9,C11,C7,C8 | C_0402_1005Metric | 6 | 0.1u
26 | J6 | DSUB-9_Male_Horizontal_P2.77x2.84mm_EdgePinOffset4.94mm_Housed_MountingHolesOffset7.48mm | 1 | USART
27 | SW1 | SW_CW_GPTS203211B | 1 | DOOR_LCK
28 | R_LDO1 | R_0805_2012Metric_Pad1.20x1.40mm_HandSolder | 1 | 330
29 | C14,C28 | C_0402_1005Metric | 2 | 100n
30 | SW3 | SW_DIP_SPSTx03_Slide_6.7x9.18mm_W8.61mm_P2.54mm_LowProfile | 1 | WIN_SW
31 | U1 | LT1528CT#PBF | 1 | LT1528CT-PBF
32 | C2 | C_0805_2012Metric | 1 | 100n
33 | U6 | DLP-RFID2 | 1 | ~
34 | C30 | C_1206_3216Metric | 1 | 10n
35 | R8 | R_0805_2012Metric | 1 | 120
36 | J12 | TerminalBlock_MetzConnect_Type011_RT05504HBWC_1x04_P5.00mm_Horizontal | 1 | WIN_SW
37 | J1 | TerminalBlock_MetzConnect_Type011_RT05502HBWC_1x02_P5.00mm_Horizontal | 1 | PowerIN
38 | R3 | R_0805_2012Metric | 1 | 10k
39 | U3 | TCAN3413DR | 1 | TCAN334D
40 | C18,C21,C17,C19,C20 | C_0805_2012Metric | 5 | 4.7u
41 | R1 | R_0805_2012Metric | 1 | 0

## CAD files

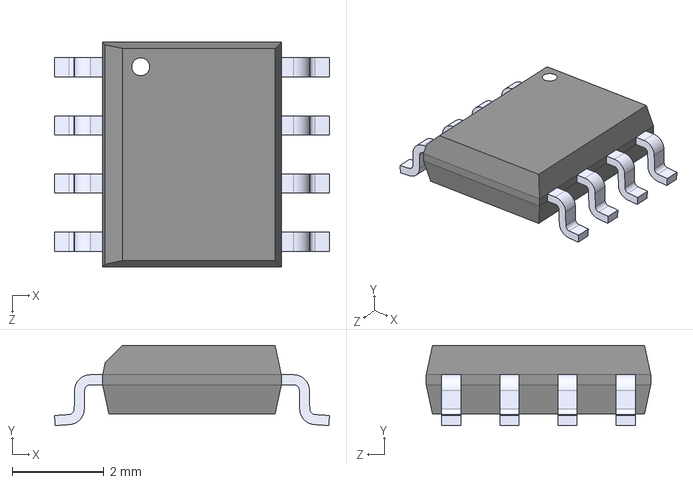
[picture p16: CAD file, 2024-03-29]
DIJOUS_4_PORTES-master/PCB/kicad_models/TCAN3413DR.step
6.00 x 1.75 x 4.90 mm

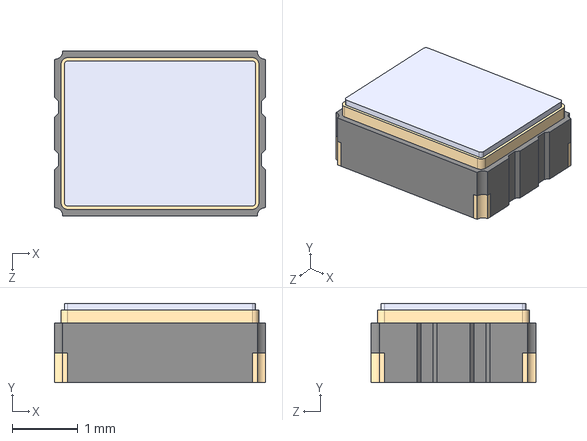
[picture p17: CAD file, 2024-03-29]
DIJOUS_4_PORTES-master/PCB/kicad_models/ECS-3225SMV-080-GP-TR.step
3.20 x 1.20 x 2.50 mm

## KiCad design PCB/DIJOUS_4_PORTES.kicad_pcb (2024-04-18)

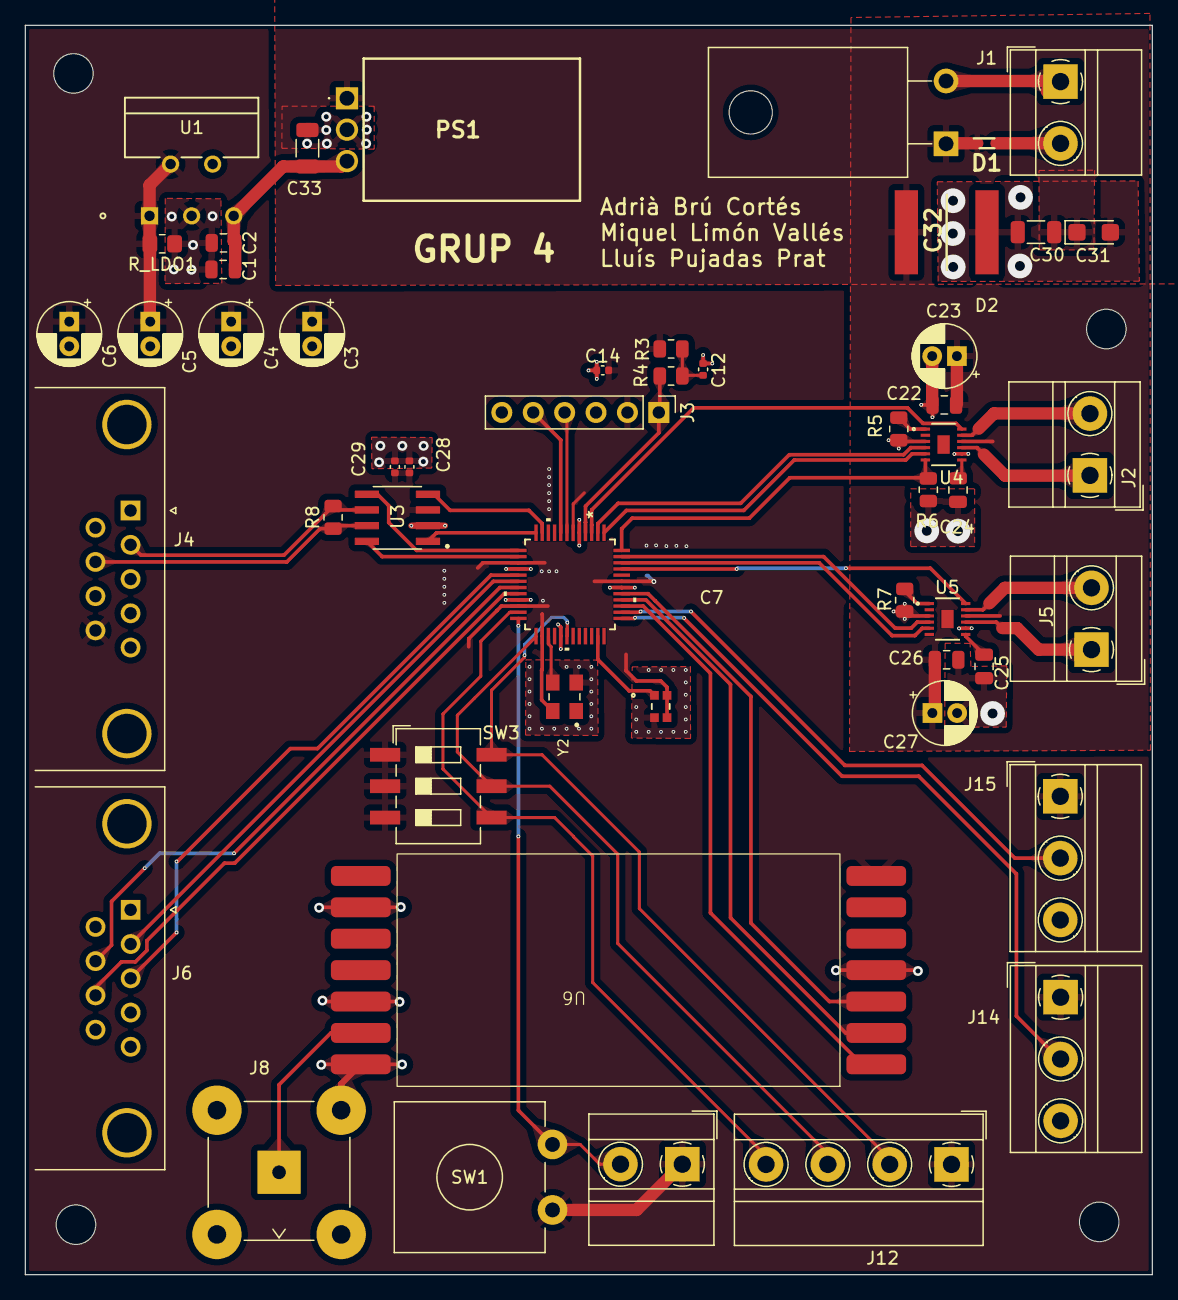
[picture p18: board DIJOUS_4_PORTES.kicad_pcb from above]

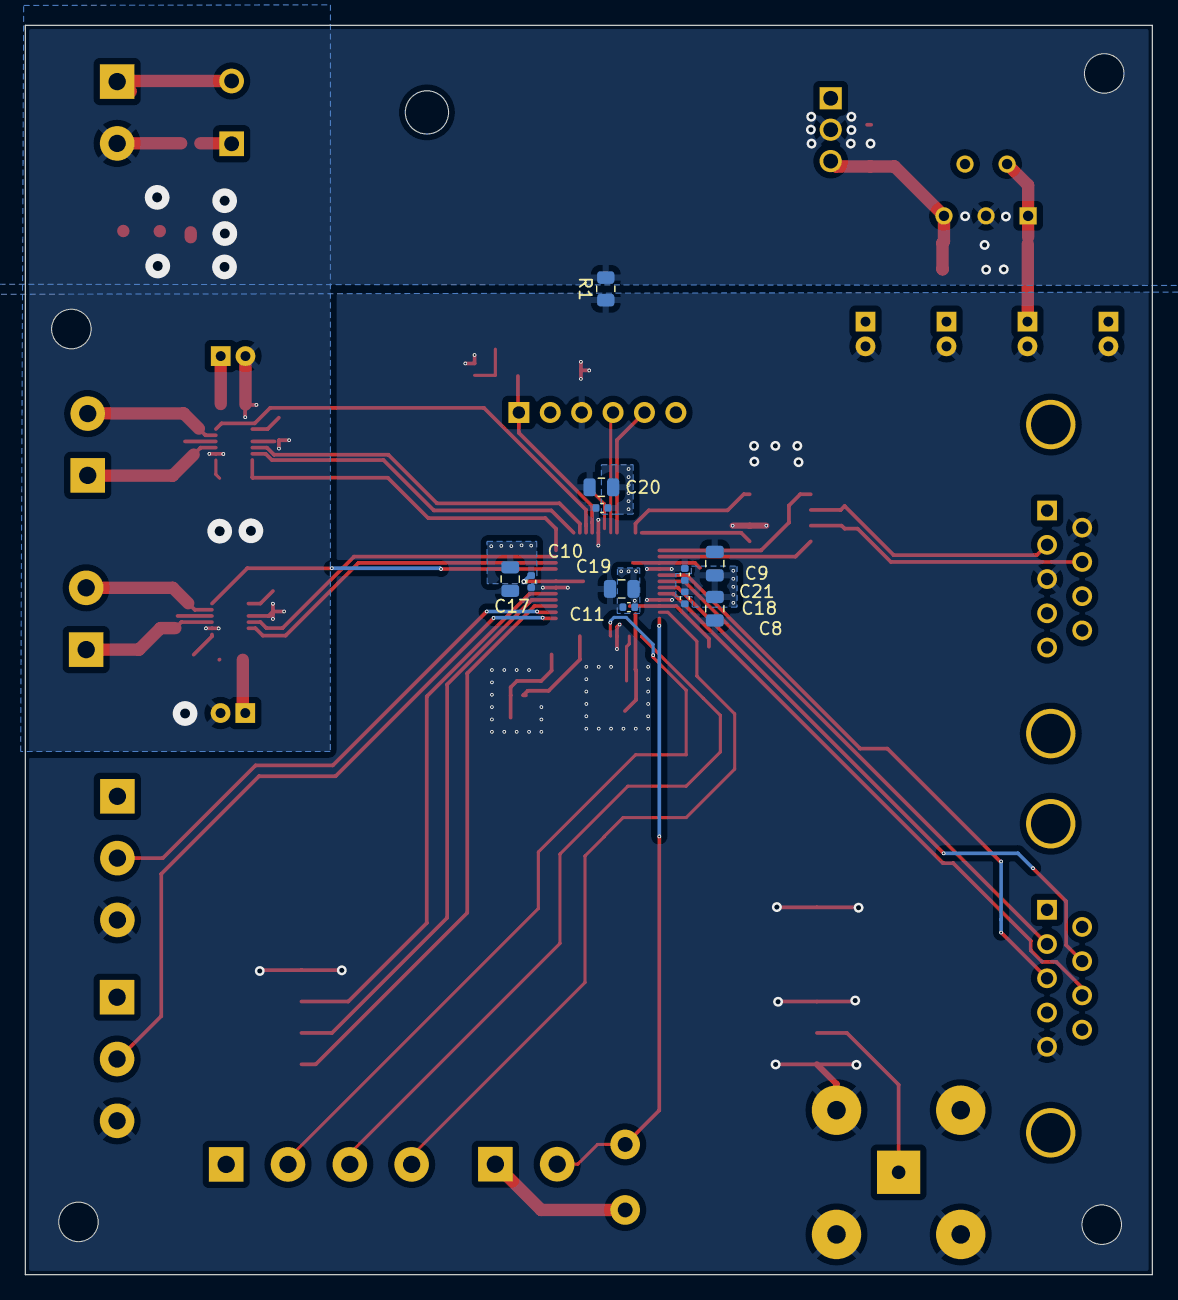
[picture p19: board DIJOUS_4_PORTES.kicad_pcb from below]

Board: 2 copper layers, 91.2 x 101.1 mm, 62 parts (11 on the bottom side), 47 nets.

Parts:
C1, C22, C24, C25, C26: 1u; C_0805_2012Metric
C2: 100n; C_0805_2012Metric
C3, C4, C5, C6, C23, C27: 47u; CP_Radial_D5.0mm_P2.00mm
C7, C8, C9, C10, C11, C12: 0.1u; C_0402_1005Metric
C14, C28: 100n; C_0402_1005Metric
C17, C18, C19, C20, C21: 4.7u; C_0805_2012Metric
C29: 1u; C_0402_1005Metric
C30: 10n; C_1206_3216Metric
C31: 1u; CP_EIA-3216-18_Kemet-A
C32: 22u/50V; CAPC7563X400N
C33: 22u/10V; C_1206_3216Metric
D1: DDZ9699T-7; SODFL1608X65N
D2: BYV10MX-600PQ; TO-220F-2_Horizontal_TabDown
J1: PowerIN; TerminalBlock_MetzConnect_Type011_RT05502HBWC_1x02_P5.00mm_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
J2: OUT_WIN; TerminalBlock_MetzConnect_Type011_RT05502HBWC_1x02_P5.00mm_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
J3: ICSP; PinHeader_1x06_P2.54mm_Vertical
J4: CAN; DSUB-9_Male_Horizontal_P2.77x2.84mm_EdgePinOffset4.94mm_Hou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
J5: OUT_DOOR; TerminalBlock_MetzConnect_Type011_RT05502HBWC_1x02_P5.00mm_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
J6: USART; DSUB-9_Male_Horizontal_P2.77x2.84mm_EdgePinOffset4.94mm_Hou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
J8: RFID_COAX; BNC_TEConnectivity_1478035_Horizontal
J10: DOOR_LCK; TerminalBlock_MetzConnect_Type011_RT05502HBWC_1x02_P5.00mm_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
J12: WIN_SW; TerminalBlock_MetzConnect_Type011_RT05504HBWC_1x04_P5.00mm_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
J14: FINAL_CARRERA_UP; TerminalBlock_MetzConnect_Type011_RT05503HBWC_1x03_P5.00mm_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
J15: FINAL_CARRERA_DOWN; TerminalBlock_MetzConnect_Type011_RT05503HBWC_1x03_P5.00mm_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
PS1: P7805-2000R-S; P78032000RS
R1: 0; R_0805_2012Metric
R3: 10k; R_0805_2012Metric
R4: 1k; R_0805_2012Metric
R5, R7: 100k; R_0805_2012Metric
R6: 33k; R_0805_2012Metric
R8: 120; R_0805_2012Metric
R_LDO1: 330; R_0805_2012Metric_Pad1.20x1.40mm_HandSolder
SW1: DOOR_LCK; SW_CW_GPTS203211B
SW3: WIN_SW; SW_DIP_SPSTx03_Slide_6.7x9.18mm_W8.61mm_P2.54mm_LowProfile
U1: LT1528CT-PBF; LT1528CT#PBF
U2: PIC32MK0256MCJ048-I/Y8X; PIC32MK0256MCJ048-I-Y8X_MCH
U3: TCAN334D; TCAN3413DR
U4, U5: MAX22201ATC+; MAX22201ATC_
U6: DLP-RFID2
Y1: ASZKDV-32.768KHZ-L-T3; ASZKDV_ABR
Y2: ECS-3225SMV-080-GP-TR; OSC_ECS-3225SMV-080-GP-TR

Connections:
+3.3V: C3.1, C4.1, C5.1, C6.1, C7.1, C8.1, C9.2, C10.1, C11.1, C14.2, C17.1, C18.1, C19.1, C20.1, C21.1, C28.2, C29.1, J3.2 (VDD), J4.9, J10.1, J12.1, J14.1, J15.1, R3.2, R_LDO1.2, SW1.1, SW3.1, SW3.2, SW3.3, U1.1 (OUTPUT), U1.2 (SENSE), U2.6 (VDD), U2.15 (AVDD), U2.22 (VDD), U2.26 (VDD), U2.43 (VDD), U3.3 (VCC), U6.7 (VCC), Y1.3 (OE), Y1.4 (VDD), Y2.4 (VDD)
+5V: C1.1, C2.1, C33.1, PS1.3 (+VO), U1.5 (VIN)
+12V: C22.1, C23.1, C26.1, C27.1, C30.1, C31.1, C32.1, D1.1 (K), D2.1 (K), PS1.1 (+VIN), U4.10 (VM), U5.10 (VM)
/DIGITAL/MCLR_VDD: C12.1, R3.1, R4.2
/DIGITAL/RF_out: J8.1 (In), U6.13 (RF_Out)
/DIGITAL/clk1i: U2.27 (OSCI/CLKI/AN49/CVD49/RPC12/RC12'), Y2.3 (OUTPUT)
/DIGITAL/clk2i: U2.35 (SOSCI/RPC13/RC13), Y1.1 (OUTPUT)
/PWR IN/pwin: D2.2 (A), J1.1
CAN_N: J4.2, R8.2, U3.6 (CANL)
CAN_P: J4.7, R8.1, U3.7 (CANH)
CAN_RX: U2.11 (PGD3/VREF-/OA2IN-/AN2/C2IN1-/RPB0/CTED2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), U3.4 (RXD)
CAN_SHDN: U2.13 (PGC1/OA1IN+/AN4/C1IN1+/C1IN3-/C2IN3-/RP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), U3.5 (SHDN)
CAN_STB: U2.14 (PGD1/OA1IN-/AN5/CTCMP/C1IN1-/RTCC/RPB3/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), U3.8 (STB)
CAN_TX: U2.12 (PGC3/OA1OUT/VREF+/AN3/C1IN4-/C4IN2-/RPB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), U3.1 (TXD)
DOOR_IN1: U2.47 (RPB13/PWM2L/CTPLS/RB13), U5.4 (IN1)
DOOR_IN2: U2.46 (RPB12/PWM2H/RB12), U5.5 (IN2)
DOOR_OUT1: J5.2, U5.11 (OUT1)
DOOR_OUT2: J5.1, U5.9 (OUT2)
FINAL_CARRERA_DOWN: J15.2, U2.38 (RPC6/PWM6H/RC6)
FINAL_CARRERA_UP: J14.2, U2.37 (TMS/OA5IN-/AN27/CVD27/LVDIN/C5IN1-/RPB9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)
GND: C3.2, C4.2, C5.2, C6.2, C7.2, C8.2, C9.1, C10.2, C11.2, C12.2, C14.1, C17.2, C18.2, C19.2, C20.2, C21.2, C28.1, C29.2, J3.3 (VSS), J4.3, J4.6, J6.5, J8.2 (Ext), J14.3, J15.3, R1.1, U2.5 (VSS), U2.16 (AVSS), U2.21 (VSS), U2.29 (VSS), U2.42 (VSS), U3.2 (GND), U6.4 (GND), U6.9 (GND), U6.12 (GND), U6.14 (GND), Y1.2 (GND), Y2.2 (GND)
GNDPWR: C1.2, C2.2, C22.2, C23.2, C24.2, C25.2, C26.2, C27.2, C30.2, C31.2, C32.2, C33.2, D1.2 (A), J1.2, PS1.2 (GND), R1.2, R5.2, R6.2, R7.2, R_LDO1.1, U1.3 (GND), U4.3 (GNDP), U4.8 (GNDA), U5.3 (GNDP), U5.8 (GNDA)
ISEN_WIN: R6.1, U2.48 (TDO/PWM4H/RA10), U4.6 (ISEN)
LOCK: J10.2, SW1.2, U2.24 (FLT15/RPB4/SCL2/RB4)
unnamed: R5.1, U4.1 (ILIM)
unnamed: C24.1, U4.7 (V18)
unnamed: R7.1, U5.1 (ILIM)
unnamed: C25.1, U5.7 (V18)
PGECx: J3.5 (PGC/ICSPCLK), U2.8 (AN9/CVD9/RPA11/FLT14/RA11)
PGEDx: J3.4 (PGD/ICSPDAT), U2.7 (AN10/CVD10/RPA12/FLT13/RA12)
RFID_IN: U2.39 (RPC7/PWM6L/RC7), U6.1 (DataToHost)
RFID_OUT: U2.40 (RPC8/PWM5H/RC8), U6.2 (DataFromHost)
RFID_RST: U2.41 (RPC9/PWM5L/RC9), U6.3 (Rst)
UART_CLK: J6.7, U2.19 (OA3IN+/AN8/CVD8/C3IN1+/C3IN3-/RPC2/FLT3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)
UART_RX: J6.2, U2.18 (OA3IN-/AN7/CVD7/C3IN1-/C4IN1-/RPC1/RC1)
UART_TX: J6.3, U2.17 (OA3OUT/AN6/CVD6/C3IN4-/C4IN1+/C4IN4-/RP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)
WIN_IN1: U2.2 (RPB14/PWM1H/RB14), U4.4 (IN1)
WIN_IN2: U2.1 (TCK/RPA7/PWM4L/RA7), U4.5 (IN2)
WIN_OUT1: J2.2, U4.11 (OUT1)
WIN_OUT2: J2.1, U4.9 (OUT2)
WIN_SW1: J12.2, SW3.6, U2.30 (RD8)
WIN_SW2: J12.3, SW3.5, U2.25 (OA5IN+/AN24/CVD24/C5IN1+/C5IN3-/RPA4/RA4)
WIN_SW3: J12.4, SW3.4, U2.23 (TDI/DAC2/AN26/CVD26/RPA8/SDA2/RA8)
/FAULT_DOOR: U2.45 (RPB11/PWM3L/RB11), U5.12 (*FAULT)
/FAULT_WIN: U2.3 (RPB15/PWM1L/RB15), U4.12 (*FAULT)
/MCLR: J3.1 (~MCLR/VPP), R4.1, U2.4 (MCLR#)
/UART_CTS: J6.8, U2.20 (AN11/CVD11/C1IN2-/FLT4/RC11)

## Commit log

2024-03-29 list v1
    [component_list.xlsx]
2024-03-29 list v2
    [component_list.xlsx]
2024-03-29 change LDO
    [component_list.xlsx]
2024-03-29 add models
    [ECS-3225SMV-080-GP-TR.step, TCAN3413DR.step]
2024-03-30 schematic wip
    [DIJOUS_4_PORTES.kicad_sch, alimentacio.kicad_sch, digital.kicad_sch]
2024-03-31 falta RFID i final de carrera
    [DIJOUS_4_PORTES.kicad_sch, alimentacio.kicad_sch, digital.kicad_sch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]
2024-03-31 change RX to TX error
    [digital.kicad_sch]
2024-04-03 correct schematic + README
    [alimentacio.kicad_sch, digital.kicad_sch, outputs.kicad_sch]
2024-04-03 add button controls
    [digital.kicad_sch, outputs.kicad_sch]
2024-04-04 sparse changes
    [digital.kicad_sch, outputs.kicad_sch]
2024-04-04 change file structure
    [DIJOUS_4_PORTES.kicad_sch, digital.kicad_sch, motors.kicad_sch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]
2024-04-04 add current to linear actuator
2024-04-04 changed to DCDC 3.3V, added extra bit for window ctrl + misc corrections
    [alimentacio.kicad_sch, digital.kicad_sch, motors.kicad_sch]
2024-04-04 added all components
    [DIJOUS_4_PORTES.kicad_pcb, alimentacio.kicad_sch, digital.kicad_sch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]
2024-04-04 power plane done
    [DIJOUS_4_PORTES.kicad_pcb, alimentacio.kicad_sch, digital.kicad_sch]
2024-04-06 start digital
    [DIJOUS_4_PORTES.kicad_pcb, digital.kicad_sch]
2024-04-08 added LDO from DC/DC
    [alimentacio.kicad_sch]
2024-04-08 changed clks, pwr
    [DIJOUS_4_PORTES.kicad_pcb, alimentacio.kicad_sch, digital.kicad_sch]
2024-04-09 canvis a sortides de potencia
    [DIJOUS_4_PORTES.kicad_pcb, digital.kicad_sch, motors.kicad_sch]
2024-04-09 correcció missclick capacitat
    [digital.kicad_sch]
2024-04-09 netclasses esquematic
    [digital.kicad_sch, motors.kicad_sch]
2024-04-09 Netclasses Layout i canvis de GNDPWR a GND al layout d'alimentació
    [alimentacio.kicad_sch]
2024-04-10 first PCB done, need to correct vias and solve all DRC errors
    [DIJOUS_4_PORTES.kicad_pcb, DIJOUS_4_PORTES.kicad_sch, digital.kicad_sch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]
2024-04-10 correccions diverses
    [DIJOUS_4_PORTES.kicad_pcb]
2024-04-10 correccions de pista
    [DIJOUS_4_PORTES.kicad_pcb]
2024-04-10 canvis i arreglos
    [DIJOUS_4_PORTES.kicad_pcb, digital.kicad_sch]
2024-04-10 Solució d'errors DRC
    [DIJOUS_4_PORTES.kicad_pcb, alimentacio.kicad_sch]
2024-04-10 Add files via upload
    Arreglat DRC i afegit noms
    [DIJOUS_4_PORTES.kicad_pcb]
2024-04-10 matrius de gnd
    [DIJOUS_4_PORTES.kicad_pcb]
2024-04-15 PCB LAYOUT 2.0 - rearranged uc pins, changed smd Cs to ceramic
    [DIJOUS_4_PORTES.kicad_pcb, alimentacio.kicad_sch, digital.kicad_sch]
2024-04-17 PCB versió2
    [DIJOUS_4_PORTES.kicad_pcb, DIJOUS_4_PORTES.kicad_sch, ECS-3225SMV-080-GP-TR.step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]
2024-04-18 correccions joan
    [DIJOUS_4_PORTES.kicad_pcb]
2024-04-18 parell diferencial
    [DIJOUS_4_PORTES.kicad_pcb]
2024-04-18 excel components
    [component_list.xlsx]
2024-04-18 separate planes
    [DIJOUS_4_PORTES.kicad_pcb]
2024-04-18 excel pressupost
    [component_list.xlsx]
2024-04-22 Resistències modificades a l'excel
    [component_list.xlsx]
2024-04-24 Excel 50xpcb
    [component_list.xlsx]
2024-04-24 Ara si
    [component_list.xlsx]
2024-04-24 complete budget
    [DIJOUS_4_PORTES.csv, component_list.xlsx, digital.kicad_sch]
2024-04-25 updated budget
    [component_list.xlsx]
2024-04-25 correcio pressupost
    [component_list.xlsx]
2024-04-25 gràfics gut
    [component_list.xlsx]
